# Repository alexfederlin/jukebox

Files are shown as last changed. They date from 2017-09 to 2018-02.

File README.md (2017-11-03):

# Kid's Jukebox
Here you will find all resources I used to build my RFID jukebox project.
Jukebox

(All pictures shown here are part of this [Google Photo Album](https://photos.app.goo.gl/Ljl14TL1XvXTWub62))

## TL;DR
It's a box which reads an RFID card, translates it into a folder on the Raspi's SD Card and instructing mpd to play it. You also have a display, buttons and a knob.

SW is written in bad node.js. If you just want to use it, all you need is to put the hardware together. There are Ansible playbooks which do all of the Raspi configuration and installation in the repo.
For building the hardware, there are complete instructions below and building plans in the repo. 

## Inspiration
The idea is not new. Instead of having CDs scratched in no time or paying ridiculous amounts of money for commercial RFID story players (has anyone ever bought a tonies? Really?), I decided to roll my own.

There are several good ideas for building RFID Jukeboxes out there:

They range from minimal viable products:
https://mwiedemeyer.de/blog/post/Raspberry-Pi-Jukebox-fur-Kinder

To quite sophisticated ones.
- http://www.forum-raspberrypi.de/Thread-projekt-jukebox4kids-jukebox-fuer-kinder
- http://www.forum-raspberrypi.de/Thread-projekt-rfid-media-player

## Parts
I decided the minimum for me would be the following in terms of hardware (all prices indicated are approximately what I paid in 2017, including shipping where applicable)
### Basics
- Box (Zeller-Holzkisten 30x20x15) - 6,50 EUR - hardware store
    - covers for the sides (I used metal mesh from a beat up IKEA waste paper basket)
    - front (7mm plywood from the hardware store) 
    - some more 1x2 cm wooden slats and some more plywood to mount the internal components
- Speakers, Amp (still had some small active speakers lying around)
- Raspi (still had a v1 lying around)
- Power supply (15W/5V MeanWell, RS-15-5) -  10 EUR - Amazon
- RFID reader (RDM630 UART 125KHz EM4100) - 8 EUR - Amazon
- another RFID reader for provisioning (SODIAL(R) USB RFID DeskTop ID Card Reader) - 5 EUR - Amazon
- 3 Arcade buttons (2 blue, 1 red) -  10 EUR - ebay
- 1 rotary encoder (KY-040 incl. nut) - 3 EUR incl shipping - ebay
- Ground loop insulator (AUKEY) - 10 EUR - Amazon https://www.amazon.de/gp/product/B01LX0H29W

### Small parts
- Ethernet connector (0.3m RJ45 Plug to Jack Panel Mount) - 4 EUR - ebay 
- USB cable (A to L shaped B connector) - 4 EUR - ebay
- ICE Socket C14 Inlet with switch and fuse - 4 EUR - ebay
- Some M3 screws and nuts - 9 EUR - ebay
- Resistors, capacitors - 2 EUR - ebay
- Jumper cable (some shorter, some up to 30 or 40 cm)
- heat shrinking tube

No arduino, no display.

However, what fun would it be without an Arduino?

So I scrapped that idea, or rather, I extended it.

### Extension
- Arduino Uno (used to control RFID reader, Buttons, Rotary dial, eventually an LCD) 23 EUR - Amazon
- Proto Shield V5 Prototyping Board für Arduino Uno - 6 EUR - ebay
- Display (16x2 Zeichen + I2c Modul) - 7 EUR - ebay
- Relais 2-Channel 5V Relais with Optokoppler - 5 EUR - ebay
- Wifi Stick (Edimax EW-7811Un) - 7 EUR Amazon

### Price
So, if you tally this up, not exactly cheap. 
Bare bones 75 EUR
Extensions 48 EUR
Total: 123 EUR

And this is without the Raspi, speakers and amp, since I had all of this still lying around...

Add to that maybe 100 hours of research, design, building, programming... But the learning experience was priceless :-)

## Hardware
Putting together the hardware components was a combination of woodwor and electronics. With this you have to choose the order of what you're doing wisely. Else you end up with a lot of wood shavings on your electronics parts...
### Box
A basic wooden box from the hardware store (Bauhaus).  In each corner I glued some 1x2cm wooden slates. These were cut to length so that the 7mm plywood front ended up flush with the rim of the box. 
On the sides of the box are holes, so you can carry it (if you use it as an actual storage box. They're handy for ventilation, but you'll want to cover them to keep out sticky things and pokey fingers. I cut up a beat up steel mesh waste paper basket from Ikea and upcycled the mesh for this purpose. I used a staple gun to fix it to the inside of the box.

#### Front Panel
I had the plywood for the front cut to size in the hardware store. If you have a buzz saw, you can probably do it yourself, but with a jigsaw - forget it. The front I set into the box and is screwed into the slats in the corners.
Before you do that, all the components have to be fixed to it of course. The layout of the front panel you can find as a draw.io sketch in the Documentation folder of this repo.

Front panel in intermediate stage

The front panel holds 
- the speakers
- amp
- display
- 3 arcade buttons (forward, back, play/pause)
- a rotary encoder (volume)
- the RFID reader along with its Antenna 
- Arduino.

Having all these components together on the front panel has the advantage that there are only 4 cables connecting the front panel and the back plane: 
- USB cable (Arduino - Raspi)
- Audio cable (Amp - Raspi)
- Power for the Amp (throught the Relais)

##### Tools and manufacturing
Front panel

The front panel requires a number of holes to be drilled and cut out. Tools used were
- drill 3.5 mm
- sink bit 3mm to get the screws flush with the wood
- Forstner drill 30 mm for Arcade buttons
- Holesaw 45mm for speakers
- large drill and jigsaw for the display cutout
- industrial rotary tool (Proxxon IBS) for removing some material on the back side to fit the display

shaving on the back

When cutting out the holes for the speakers - cut the big holes first, before you drill the screw holes. Once you have the big holes in place, put the speakers on there and mark where the screw holes need to go. I did it all at once just with measurements and of course my speakers now sit off-center on the holes...

#### Back plane
As back plane I used another piece of plywood. This one I cut myself, because you can't see it anyway, so it's ok if the edges are a bit squiggly. I glued some scrap pieces of plywood to the bottom of the box so it's raised up a bit. I put in some screws at an angle that go into the corner slats to hold it in place.

The picture below was taken when I tried to figure out what goes where on the backplane. Nevermind the funny cutout in the upper part. I was practicing for the display cutout on the front...
Backplane intermediate

The backplane only holds
- the Raspberry
- power supply
- power relais

I used the lower snap-in half of a Raspi case to hold the Rasperry. This is quite nice because only the case is screwed to the back plane and the Raspi itself is easily removed. That makes e.g. changing the SD card much easier.
The other components are just strapped to the plywood using cable ties threaded through holes I drilled into the plywood.

There is also a cut out for the only components that are actually attached to the box itself:
- the C14 power inlet
- the RJ45 panel mount
- the power button i didn't get around to installing

Back

### Power
The power setup is not quite finished. The inital plan was to have a power button on the back which shuts down the raspi and powers off the amp with a short press. Powering on the raspi would have to be done by physically cutting the power.
I even have the script in the repo which would have to run on the raspi, watching for the button to be pushed. But, alas, I couldn't be bothered.
I still wired the amp to the relais (which is controlled by the Raspi), so in theory I could turn off the amp if no music is playing for a while...

### Electronics

Now that we got all of that boring woodwork out of the way, now for the fun part...
Full

#### Arduino

There is a Fritzing sketch in the Documentation folder of this project...

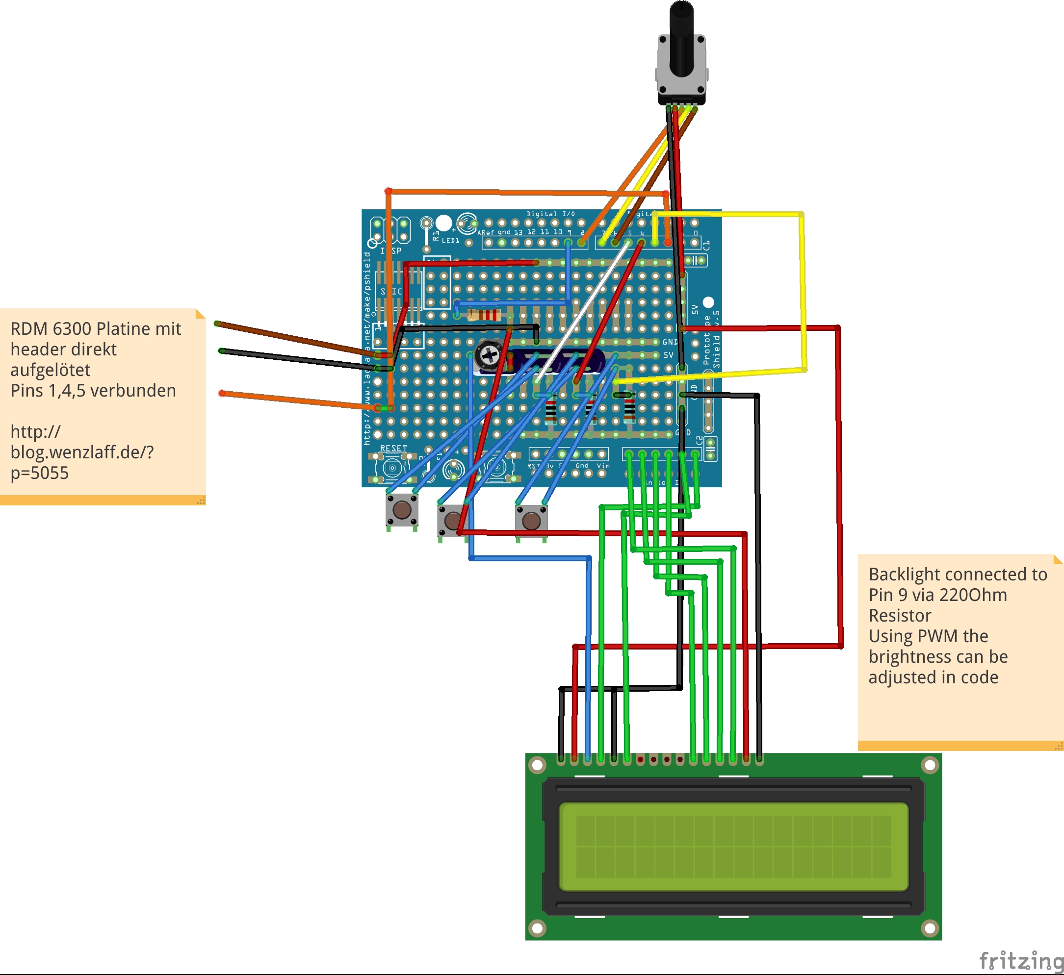
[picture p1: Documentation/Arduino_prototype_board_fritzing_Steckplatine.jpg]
Fritzing


There are a couple of things to connect to the Arduino:
- 3 Buttons
- a KY40 Rotary Encoder
- a display
- and of course the RFID reader

I use the prototyping board that you can plug on top of the Arduino to solder all my circuitry. It's all a bit small and it's not pretty, but it is absolutely doable (I'm not really a wizard with the soldering iron).And it's probably less prone to cables coming loose than breadbords - which you also would have to glue to the front panel somehow...

Arduino

##### Buttons
I decided to go with a hardware debounce for the buttons. For this I used a 1uF capacitor and a 10kOhm resistor. Why do it in hardware? Because I can. In retrospect, it probably would have been easier to do it with less hardware elements for space reasons, but hey, it works.

##### Rotary Encoder
I had a bit of a hard time with the rotary encoder for adjusting the volume. I found out that there are different hardware versions available. Some have a thread and a nut with which you can fix them to a panel. Some don't...
I also tried HW debouncing, but that didn't work. I tried a gazillion libraries that all claim to do SW debouncing for rotary encoders... luckily I found one that worked. More on that in the SW section.

##### Display
The display is a fun thing to play with. In the final product it's of less use than I thought. I tried scrolling text, but it looks horrible. So you're really confined to 2x16 characters. And putting some sensible stuff on there is more effort than I was prepared to spend to this point.
All the pins needed to drive the display are connected to the Arduino using long jumper wires. I soldered a pin strip to the display board to be able to just plug them on.

##### RFID reader
The RFID reader comes with a small board of its own which you need to connect. Since I was too lazy to figure out a way to secure it to the front panel, I simply soldered it onto the prototyping board and connected it up that way (the upside down board one the left on the picture above).
I used hot glue to stick the RFID antenna to the front panel and to stabilize the connection between the actual antenna and the cable leading to the reader board. These braids are so fine I was worried they'll break before I can fix them.

## Software
The whole thing is based on the Music Player Daemon mpd. In theory you scrap the whole interface on the box and just control the whole thing with [M.A.L.P.](https://play.google.com/store/apps/details?id=org.gateshipone.malp) or some other mpd remote control app. 
But of course that wouldn't be as much fun. So we have to roll our own for hooking up all that interface stuff.

### General Architecture
So in general, there are 4 components that interact somehow:
- The Arduino - handling the front end user interface and presentation layer (aka Display)
- The Arduinogateway - the code translating user input from the Arduino to commands to the mpd (and info back to the display)
- The Playlist Mapper - handling the database to translate an RFID tag to a path which the mpd can play
- The mpd - playing the actual music

### Arduino Sketch
The Arduino folder is actually a complete [platform.io](http://platformio.org/) project. It enables you to write your changed Arduino sketch stright to the Arduino from the Raspberry. No more clunky Arduino IDE. It will even download and install all the necessary libraries automatically. I love it.

Anyway, there's quite a bit going on in the sketch, so let's check it out component by component
#### Display
I use the [LiquidCrystal](https://www.arduino.cc/en/Tutorial/LiquidCrystalDisplay) [Library](https://www.arduino.cc/en/Reference/LiquidCrystal), which is easy enough to use. As I mentioned, scrolling looks horrible because the display is so slow to switch on and off. Pixels which are used from one step to the next remain really bright, while the others are pretty dim. The result is pretty much garbled. Anyway, if you want to try it, [this sketch proposed by Goet](https://forum.arduino.cc/index.php?topic=216486.msg3338710#msg3338710) seems to work pretty well...

One thing that I think is pretty neat is the automatic backlight dimming I implemented using the PWM pin on the Arduino. By hooking up the backlight pin of the displa to one of the "analog" pins of the Arduino, I'm able to dim the backlight in the code. It goes bright at any input, and dims after there hasn't been any input for 10 seconds.

#### Serial Connection
Using SoftwareSerial for the serial connection to the Raspi through the USB cable. The Arduino is also powered through the USB cable.
The protocol between the Arduino and the Raspi (Arduinogateway process) is extremely simple. There are 5 commands which the Arduino can send to the Raspi:

- CMD: setvol xx
- CMD: previous
- CMD: next
- playpause
- RFID: xxxx

The ones prefixed by CMD: are piped verbatim to the mpd by the Arduinogw. The others need to be handled separately.

playpause: The Arduino does not know whether the player is currently playing or not (I guess you could implement it in a way that the Arduino gets informed of the state and stores that state. But whatever). So if the play/pause button is pressed, this tells the Arduinogw process that it should toggle the play/pause state of the player. More on that in the ArduinoGW section

RFID: xxxx: with this the Arduinogw process needs to find out which command/playlist is attached to that RFID before being able to send it.

Everything else that is sent will just be logged by Arduinogw. 

For the return communication, I decided to terminate each command or piece of information sent to the Arduino with a new line. That way I can deal with incoming messages in one piece and don't have to manually find out if what I've received so far makes sense or not. Everything the Arduino receives on the serial connection is printed on the display and sent back to Arduinogw.

#### Rotary Encoder
Rotary Encoders are pretty cool. [Here is how they work](http://henrysbench.capnfatz.com/henrys-bench/arduino-sensors-and-input/keyes-ky-040-arduino-rotary-encoder-user-manual/).
But oh boy, getting them to work properly is not easy. I tried many libraries for rotary encoders. None really worked. Then I found the [stuff the boolrules posted](https://forum.arduino.cc/index.php?topic=242356.msg2308019#msg2308019). I have no idea what it does, but I was able to integrate it and it works like a treat. It has two modes (interrupt and polling), I use it in polling mode and have thrown away the unused interrupt code.
Some code in the loop section takes care that you cannot turn the volume up to 11. Well actually you can increment and decrement in steps of 10 between 0 and 100. Why not 1-10? Laziness. That way I can push the value through all the way to mpd.

#### Buttons
The button stuff is pretty straight forward. There is is three buttons connected to three input pins. If a button is pressed, we send the appropriate command. And we do not send any other button event until that initial button is released. Mainly, this prevents repeatedly sending the same command as long as the button is pushed. As a side effect, pushing several buttons at once does not have any effect. There is only one button command sent.

#### RFID reader
The RFID reader code needs to deal with some special cases. 
The RFID reader will repeat the RFID it has in range every couple 100 ms as long as it is in range. Of course we only want to send the command to play a given RFID tag only once. So there is a blocktimer of 5 seconds during which the same RFID tag is ignored.
At the same time I found that the  RFID reader sometimes spits out random RFID tags. But these are not repeated. So if a RFID tag is read, it will actually be ignored the first time. Only if the RFID reader signals again within 1 second, we actually look at what has been sent.

The format in which the RFID reader signals the IDs got me stumped initially, since it just wasn't what I expected. Also my hex is quite rusty. It takes some bit shifting to actually get a decimal number out of what you get from the RFID Reader.

##### Expectation
At first I somehow expected the individual decimal digits to be hex encoded. So I expected something like this:

Consider the following RFID tag in decimal: 0007616525
In ASCII this would actually be the following binary octets:

    0011 0000 
    0011 0000 
    0011 0000 
    0011 0111 
    0011 0110 
    0011 0001 
    0011 0110 
    0011 0101 
    0011 0010 
    0011 0101

Now we remove the leading 0011s

    0000 
    0000 
    0000 
    0111 
    0110 
    0001 
    0110 
    0101 
    0010 
    0101

and concatenate the remaining half octets (nibbles) together to new bytes

    0000 0000  0x0
    0000 0111  0x7
    0110 0001  0x61
    0110 0101  0x65
    0010 0101  0x25

##### Reality

In reality, what you get from the RFID reader is of course the complete number (7 mio 616 thousend 525) in hex:

    0111 0100  0x74
    0011 1000  0x38
    0000 1101  0x0D

The format in which you get it is an array of bytes, so actually:

    data[1] = 0x00
    data[2] = 0x74
    data[3] = 0x38
    data[4] = 0x0D

So, in order to convert this to a usable decimal number (because that's what I want, the RFID is printed on the card in decimal as well), there is a bit of casting and bit shifting to do.

     unsigned long result = ((unsigned long int)data[1]<<24) + ((unsigned long int)data[2]<<16) + ((unsigned long int)data[3]<<8) + data[4];
     
First of all, we need to cast all of this to unsigned long int in order to be even able to shift it that far.
So we convert the byte in data[1] to an unsigned long and shift it by 24 bits to the left. Not really exciting because it's all 0.
But now we take the contents of data[2] and shift it 16 bits. So we take

    0111 0100

convert it to

    0000 0000 0000 0000 0000 0000 0111 0100
    
and then bit shift it by 16 bits:

    0000 0000 0111 0100 0000 0000 0000 0000

to that we add the contents of data[3], shifted by 8 bits:

    0000 0000 0111 0100 0011 1000 0000 0000

And then we also add the contents of data[4]:

    0000 0000 0111 0100 0011 1000 0000 1101
    
So, if we output this in its decimal representation we get what we want...

### Raspberry

#### Arduino Gateway

This is the main controlling component of the Jukebox. The actual playback of media files is handled by mpd.
This process listens to the input coming from the Arduino on the serial connection.
The commands are partly passed on directly to mpd, partly they are pre processed before the required requests are sent to mpd

There are three types of messages that can come from the Arduino
1. button presses
   button presses can result in three different messages
   - prev
   - next
   - playpause
   The first two can be put through to the mpd server. Playpause first needs to determine the current status of playback (play, stop, pause) and will then send either 
   - pause (if current status is play) 
   - play (if current status is anything else)

2. Volume messages
   volume messages are sent by the Arduino the form of volume/<value>
   This is the format expected by mpd and can be sent straight on
3. RFID reads
    If an RFID tag is scanned the message will look like: "RFID: <rfidTag>"
    First of all, we need to figure out which playlist is connected to this RFID tag. This is done by the process playlistmapper, listening on the given port and expects the RFID tag. It will reply with the appropriate playlist/folder name which will be sent to mpd.

Requirements:
- mpd must be running and it's library up to date
- playlistmapper must be running and configured to translate RFID tags to playlists present in mpd

#### Playlist mapper

Playlistmapper is a simple web server based on nodejs express which also interacts with a DB backend (a very simple file handled by nedb).
The DB stores the relation between the RFID tags and the playlist/Folder names. 
It exposes a REST interface which enables querying for a certain RFID tag.
The reply is provided in the form of a JSON String including the RFID tag as well as the playlist name: {"rfid":"7616525","playlist":"plA"}

## Deployment
If you have a Linux or Mac system, you can just follow the instructions below. If you're on Windows, you'll have to make Ansible run as Control node [somewhere somehow](http://www.tomsitpro.com/articles/how-to-use-ansible-on-windows,1-3479.html). 

1. On your main PC: install Ansible
2. PC: clone this git repo
3. Raspi: install latest Raspian light
3. Raspi: [enable ssh access](https://www.raspberrypi.org/documentation/remote-access/ssh/) and make sure you can login to the Raspi from your main PC
4. PC: make sure you have an ssh key and install it on the Raspi: `cat ~/.ssh/id_rsa.pub | ssh pi@raspberry 'mkdir .ssh && cat >> .ssh/authorized_keys'` or simply `ssh-copy-id pi@raspberry`
5. PC: enter the IP of your raspi in the ansibles inventory
6. PC: start the playbooks in order 1-3. 

### Ansible Playbooks
- 01:
  - set password of user pi to: jukebox
  - force apt to use IP4 (else apt installation does not work for me)
  - force audio through 3,5mm jack
  - do apt update / upgrade and install several packages
  - download and install node.js 7.9.0
  - instructs mpd to update its database
- 01a: You can skip 01a if you do not have an extra partition for your music (see multi-partition setup below).
- 02: clone this git repo and install the necessary nodejs modules
- 03: Sets up the necessry services to be started at boot and starts them
- 04: is only needed if you want to use rsync to sync a music folder on your main (or other) PC to the jukebox.

If all the playbooks went through without error, everything should be installed and configured and all services should be up and running on the raspberry.
There are a couple of optional playbooks which 
- opt01/a: allow you to switch back and forth between a USB sound card and the built-in 3.5 jack audio output
- opt02: Installs [platformio](http://platformio.net) on the raspi (for flashing your Arduino straight from the Raspi)

## Operations

## Provisioning

# Special cases
## Multi-Partition setup.
I like to have my music on another partition than the root system. In case I need to reinstall the system, I don't have to re-upload all of the music. Having multiple partitions on a raspi system is not quite as straightforward as I'd hoped. 
In general Raspbian resizes the root partition to fill the whole medium at the first boot. It does not do this, if another partition is already present on the device. In that case, the root partition of the raspi is too small to install anything extra. So you have to enlarge it manually. After doing that, the PARTUID has changed, so you need to update the /boot/cmdline.txt and /etc/fstab on your raspi system...

### WARNING - HERE BE DRAGONS
In the following I'll describe how I set it up. You'll have to think for yourself what you are doing! I take no responsibility for any wiped harddrives...

1. Download latest raspbian (
2. check if download is correct `sha256sum 2017-08-16-raspbian-stretch-lite.zip`
3. unzip raspbian image `unzip 2017-08-16-raspbian-stretch-lite.zip`
4. put on SD Card - MAKE SURE YOU SPECIFY THE CORRECT DEVICE AS of=/dev/sxx `sudo dd if=2017-08-16-raspbian-stretch-lite.img of=/dev/sxx bs=1M`
5. create additional partition on sdcard for music `fdisk /dev/sxx`
    If you start fdisk and [p]rint all partitions, you will find something like this:
```
Medium /dev/sdd: 59,5 GiB, 63864569856 Bytes, 124735488 Sektoren
Einheiten: sectors von 1 * 512 = 512 Bytes
Sektorengröße (logisch/physisch): 512 Bytes / 512 Bytes
I/O Größe (minimal/optimal): 512 Bytes / 512 Bytes
Typ der Medienbezeichnung: dos
Medienkennung: 0xee397c53

Gerät      Boot Start    Ende Sektoren Größe Id Typ
/dev/sdd1        8192   93813    85622 41,8M  c W95 FAT32 (LBA)
/dev/sdd2       94208 3621911  3527704  1,7G 83 Linux
```
or, if you want to use parted
```
$ sudo parted /dev/sdd
GNU Parted 3.2
/dev/sdd wird verwendet
Willkommen zu GNU Parted! Rufen Sie »help« auf, um eine Liste der verfügbaren Befehle zu erhalten.
(parted) p                                                                
Modell: Generic STORAGE DEVICE (scsi)
Festplatte  /dev/sdd:  63,9GB
Sektorgröße (logisch/physisch): 512B/512B
Partitionstabelle: msdos
Disk-Flags: 

Nummer  Anfang  Ende    Größe   Typ      Dateisystem  Flags
 1      4194kB  48,0MB  43,8MB  primary  fat32        LBA
 2      48,2MB  1854MB  1806MB  primary  ext4
```

As you can see, the raspi partition is only 1,7 Gb. There will most likely a lot of empty space on your device left. If you boot this now, raspian will automatically resize the root partition to take up the whole device. 

What you actually want is a root partition which is 5-6GB and another partition which takes up the remaining space on the device for your data. 

So you need to delete the root partition, recreate it with the same start boundary, but a bit larger, and then create another partition for your data taking up the rest of the space (or however much you like)

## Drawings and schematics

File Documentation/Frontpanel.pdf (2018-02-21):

# Front View

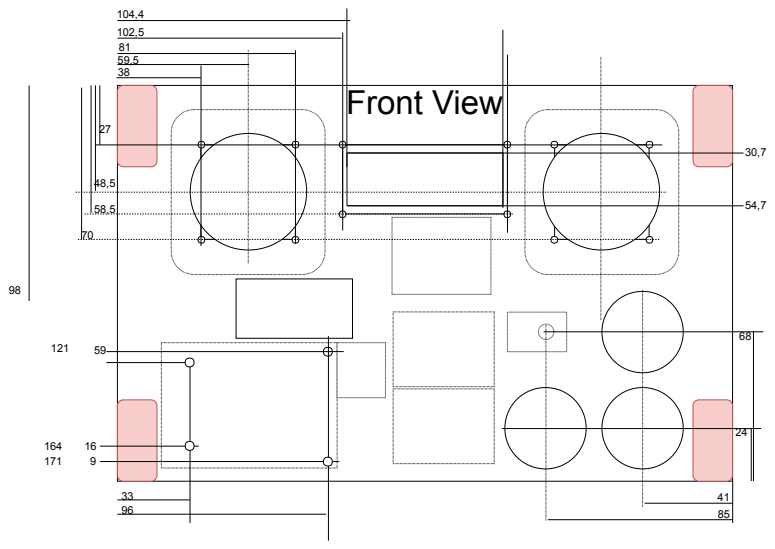
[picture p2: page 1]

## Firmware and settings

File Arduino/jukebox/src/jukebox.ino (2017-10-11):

/*
 *      based on 
 *      - Rotary Encoder: http://www.buxtronix.net/2011/10/rotary-encoders-done-properly.html
 *      - RFID Handling:  http://playground.arduino.cc/Main/RDM630RFIDReaderLibrary
 *      
 */


#include    <MsTimer2.h>
#include <SoftwareSerial.h>
#include "rdm630.h"
#include <LiquidCrystal.h>
#include <Wire.h>


// initialize the library with the numbers of the interface pins
LiquidCrystal lcd(A0, A1, A2, A3, A4, A5);
int lcdBacklightPin = 9;
#define LCDWIDTH 16
#define LCDHEIGHT 2

String pinnedString = "online";
String scrollingString = "The Jukebox is";
int pinnedRow = LCDHEIGHT / 2;
int scrollingRow =  LCDHEIGHT / 2 - 1;
int scrollingSpeed = 400;


byte playicon[8] =
{
  0b10000,
  0b11000,
  0b11100,
  0b11110,
  0b11110,
  0b11100,
  0b11000,
  0b10000
};

byte pauseicon[8]  = {
  0b00000,
  0b11011,
  0b11011,
  0b11011,
  0b11011,
  0b11011,
  0b11011,
  0b00000
};

byte stopicon[8] = {
  0b00000,
  0b00000,
  0b11111,
  0b11111,
  0b11111,
  0b11111,
  0b11111,
  0b00000
};

int lcdCurBrightness = 0;
unsigned long lcdLastRaise;

// Rotary Encoder Stuff
///////////////////////////////////////////////////////////////////////////////

#define DIR_NONE 0x00           // No complete step yet.
#define DIR_CW   0x10           // Clockwise step.
#define DIR_CCW  0x20           // Anti-clockwise step.

unsigned int A = 6;             // pins connected to the encoder (CLK)
unsigned int B = 7;             //              "                (DT)
unsigned int ISRflag = 8;       //              "                (SW)

unsigned int state;
         int count = 40;         // count each indent
         int old_count = 0;     // check for count changed
const String VOLUME = "CMD: setvol ";
String vol = VOLUME;
/*
 * The below state table has, for each state (row), the new state
 * to set based on the next encoder output. From left to right in,
 * the table, the encoder outputs are 00, 01, 10, 11, and the value
 * in that position is the new state to set.
 */

// State definitions state table (emits a code at 00 only)
// states are: (NAB) N = 0: clockwise;  N = 1: counterclockwiswe
#define R_START     0x3
#define R_CW_BEGIN  0x1
#define R_CW_NEXT   0x0
#define R_CW_FINAL  0x2
#define R_CCW_BEGIN 0x6
#define R_CCW_NEXT  0x4
#define R_CCW_FINAL 0x5

const unsigned char ttable[8][4] = {
    {R_CW_NEXT,  R_CW_BEGIN,  R_CW_FINAL,  R_START},                // R_CW_NEXT
    {R_CW_NEXT,  R_CW_BEGIN,  R_CW_BEGIN,  R_START},                // R_CW_BEGIN
    {R_CW_NEXT,  R_CW_FINAL,  R_CW_FINAL,  R_START | DIR_CW},       // R_CW_FINAL
    {R_START,    R_CW_BEGIN,  R_CCW_BEGIN, R_START},                // R_START
    {R_CCW_NEXT, R_CCW_FINAL, R_CCW_BEGIN, R_START},                // R_CCW_NEXT
    {R_CCW_NEXT, R_CCW_FINAL, R_CCW_FINAL, R_START | DIR_CCW},      // R_CCW_FINAL
    {R_CCW_NEXT, R_CCW_BEGIN, R_CCW_BEGIN, R_START},                // R_CCW_BEGIN
    {R_START,    R_START,     R_START,     R_START}                 // ILLEGAL
};





//Button stuff
///////////////////////////////////////////////////////////////////////////////

const int buttonPin_back = 3;     // the number of the pushbutton pin
const int buttonPin_play = 4;     // the number of the pushbutton pin
const int buttonPin_forward = 5;     // the number of the pushbutton pin
const int ledPin =  13;      // the number of the LED pin

int buttonState_back = 0;         // variable for reading the pushbutton status
int buttonState_play = 0;         // variable for reading the pushbutton status
int buttonState_forward = 0;         // variable for reading the pushbutton status
int sentstate = 0;


//RFID Stuff
///////////////////////////////////////////////////////////////////////////////

rdm630 rfid(2, 0);  //TX-pin of RDM630 connected to Arduino pin 2
unsigned long time;
unsigned long lastTime;
unsigned long elapsedTime;
unsigned long blocktimer;
byte lastdata[6];
bool block;


// Serial stuff
/////////////////////////////////////////////////////////////////////////////// 
String incomingString = "";


// Helper Methods
///////////////////////////////////////////////////////////////////////////////

// Timer method for Rotary Encoder polling
void T2_isr( ) {

    // Grab state of input pins.
    unsigned char pinstate = (digitalRead( A ) << 1) | digitalRead( B );

    // Determine new state from the pins and state table.
    state = ttable[state & 0x07][pinstate];

    if( state & DIR_CW )    count=count+10;        // count up for clockwise
    if( state & DIR_CCW )   count=count-10;        // count down for counterclo$

}


void lcdDim( ) {
  int lowest = 20;
  for (int fadeValue = lcdCurBrightness ; fadeValue >= lowest; fadeValue -= 5) {
    // sets the value (range from 0 to 255):
    analogWrite(lcdBacklightPin, fadeValue);
    // wait for 30 milliseconds to see the dimming effect
    delay(30);
  }
  lcdCurBrightness = lowest;
}

void lcdRaise( ) {
  int highest = 255;
  for (int fadeValue = lcdCurBrightness ; fadeValue <= highest; fadeValue += 5) {
    // sets the value (range from 0 to 255):
    analogWrite(lcdBacklightPin, fadeValue);
    delay(5);
  }
  lcdCurBrightness = highest;
  lcdLastRaise = millis();
}

void lcdDisplay(String str) {
  lcd.clear();
  lcd.setCursor(0, 0);
  lcd.print(str);
}


// read from Serialport until a CR is found
// see https://hackingmajenkoblog.wordpress.com/2016/02/01/reading-serial-on-the-arduino/
int readline(int readch, char *buffer, int len)
{
  static int pos = 0;
  int rpos;

  if (readch > 0) {
    switch (readch) {
      case '\n': // Ignore new-lines
        break;
      case '\r': // Return on CR
        rpos = pos;
        pos = 0;  // Reset position index ready for next time
        return rpos;
      default:
        if (pos < len-1) {
          buffer[pos++] = readch;
          buffer[pos] = 0;
        }
    }
  }
  // No end of line has been found, so return -1.
  return -1;
}


/* This procedure pins a given text in the center of a desired row while scrolling from right to left another given text on another desired row.
    Parameters:
    const String &pinnedText: pinned String
    int pinnedRow: desired row for pinned String
    const String &scrollingText: scrolling String
    int scrollingRow: desired row for scrolling String
    int v = scrolling speed expressed in milliseconds
*/
void pinAndScrollText(const String &pinnedText, int pinnedRow, const String &scrollingText, int scrollingRow, int v) {
  if (pinnedRow == scrollingRow || pinnedRow < 0 || scrollingRow < 0 || pinnedRow >= LCDHEIGHT || scrollingRow >= LCDHEIGHT || pinnedText.length() > LCDWIDTH || v < 0) {
    lcd.clear();
    lcd.print("Error");
    while (1);
  }
  int l = pinnedText.length();
  lcd.setCursor(l % 2 == 0 ? LCDWIDTH / 2 - (l / 2) : LCDWIDTH / 2 - (l / 2) - 1, pinnedRow);
  lcd.print(pinnedText);
  int x = LCDWIDTH;
  int n = scrollingText.length() + x;
  int i = 0;
  int j = 0;
  while (n > 0) {
    if (x > 0) {
      x--;
    }
    lcd.setCursor(x, scrollingRow);
    if (n > LCDWIDTH) {
      j++;
      i = (j > LCDWIDTH) ? i + 1 : 0;
      lcd.print(scrollingText.substring(i, j));
    } else {
      i = i > 0 ? i + 1 : 0;
      if (n == scrollingText.length()) {
        i++;
      }
      lcd.print(scrollingText.substring(i, j));
      lcd.setCursor(n - 1, scrollingRow);
      lcd.print(' ');
    }
    n--;
    if (n > 0) {
      delay(v);
    }
  }
}


// Setup
///////////////////////////////////////////////////////////////////////////////
///////////////////////////////////////////////////////////////////////////////

void setup( ) {

//initialize LCD
    lcdRaise();
    lcd.createChar(0, playicon);
    lcd.createChar(1, pauseicon);
    lcd.createChar(2, stopicon);
    lcd.begin(16, LCDHEIGHT);

  //pinAndScrollText(pinnedString, pinnedRow, scrollingString, scrollingRow, scrollingSpeed);

//  delay(2000);
  lcd.clear();
//  lcd.print("Back");

    
// initialize the Rotary Encoder
    // pins as an input
    pinMode( A, INPUT );
    pinMode( B, INPUT );
    // start interrupt polling
    MsTimer2::set( 1, T2_isr );
    MsTimer2::start( );
    state = (digitalRead( A ) << 1) | digitalRead( B );     // Initialise state.
    old_count = 0;

//set up visual feedback for button push and RFID action
    pinMode(ledPin, OUTPUT);      

// initialize the pushbutton pin as an input:
    pinMode(buttonPin_back, INPUT);
    pinMode(buttonPin_play, INPUT);     
    pinMode(buttonPin_forward, INPUT);  


// initialize RFID
    rfid.begin();
    time = millis();
    lastTime = millis();
    blocktimer = 0L;

// initialize Serial connection

    Serial.begin( 9600 );
    Serial.println( "Jukebox Input Module Online" );
    Serial.setTimeout(200);

// Print a message to the LCD.
    lcdDisplay("Jukebox Online");
//    lcd.setCursor(15,0);
//    lcd.write((uint8_t)2);
}


// Loop
///////////////////////////////////////////////////////////////////////////////
///////////////////////////////////////////////////////////////////////////////

void loop( ) {

//read from serial

  static char buffer[80];
  if (readline(Serial.read(), buffer, 80) > 0) {
    Serial.print("Data received by Arduino: >");
    Serial.print(buffer);
    Serial.println("<");
    lcdDisplay(buffer);
  }

// Rotary Encoder 
    if( old_count != count ) {
        if ( count > 100 ) {
          count=100;
          return;
        }
        if ( count < 0) {
          count=0;
          return;
        }
        vol = VOLUME + count; 
        Serial.println(vol);
        //lcdDisplay(vol);
        old_count = count;
        lcdRaise();
        lcdDisplay ("Lautstaerke: " + String(count));
    }

//Pushbuttons
  // read the state of the pushbutton value:
  buttonState_back = digitalRead(buttonPin_back);
  buttonState_play = digitalRead(buttonPin_play);
  buttonState_forward = digitalRead(buttonPin_forward);
  
  
  // check if the pushbutton is pressed.
  // if it is, the buttonState is HIGH:
  if ((buttonState_back == HIGH) && (sentstate == 0)) {     
    // turn LED on:    
    digitalWrite(ledPin, HIGH);
    Serial.println("CMD: previous");
    lcdDisplay("previous");
    sentstate = 1;
    lcdRaise();
  } 
  else if ((buttonState_play == HIGH) && (sentstate == 0)) {     
    // turn LED on:    
    digitalWrite(ledPin, HIGH);  
    Serial.println("playpause");
    //lcdDisplay("playpause");
    lcd.setCursor(15,0);
    lcd.write((uint8_t)0);
    sentstate = 1;
    lcdRaise();
  }
  else if ((buttonState_forward == HIGH) && (sentstate == 0)) {     
    // turn LED on:    
    digitalWrite(ledPin, HIGH);  
    Serial.println("CMD: next");
    lcdDisplay("next");
    sentstate = 1;
    lcdRaise();
  }
  else if ((buttonState_back == LOW) && (buttonState_play == LOW) && (buttonState_forward == LOW)){
    // turn LED off:
    digitalWrite(ledPin, LOW); 
    sentstate = 0;
  }

// RFID stuff
    byte data[6];
    byte length;

    time = millis();

    if(rfid.available()){
        digitalWrite(ledPin, HIGH);
        if ((time - lastTime) < 1000) { // used to filter out sporadic spurious IDs
          
            rfid.getData(data,length);
            // avoid continous repetition of one and the same ID while held to reader during a block time of 5 seconds
            // output only if a different ID is read or if the block is removed
            if (memcmp(lastdata,data,length) != 0 || (time-blocktimer > 5000)) { 
              //shift the bytes to their respective positions
              //explanation why casting is needed: http://www.mikrocontroller.net/topic/95708
              unsigned long result = ((unsigned long int)data[1]<<24) + ((unsigned long int)data[2]<<16) + ((unsigned long int)data[3]<<8) + data[4];              
              Serial.print("RFID: ");
              Serial.println(result);
              //lcdDisplay(String(result));
              rfid.getData(lastdata,length);
              blocktimer = millis();
              lcdRaise();
            }
        }
        lastTime = millis();
        delay(5);
        digitalWrite(ledPin, LOW); 
    }

//  lcd.setCursor(0, 1);
  // print the number of seconds since reset:
//  lcd.print(millis() / 1000);

  if (millis() - lcdLastRaise > 10000) lcdDim();

}

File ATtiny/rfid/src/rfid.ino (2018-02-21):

#include "TinyWireS.h"
#include "rdm630.h"
//#####################################################
// This code takes care of reading RFID (RD6300)
// on an ATTiny45
// It needs to be polled from the master and will 
// return a bitmap of the last read RFID (hopefully)
//#####################################################

int ledPin = 1;

rdm630 rfid(3, 4);  //TX-pin of RDM630 connected to PB3

unsigned long time;
unsigned long lastTime;
unsigned long blocktimer;

byte data[6];
byte lastdata[6];

byte i2cAddress = 20;
int i2cSendStep = 0;
bool i2cSendComplete = true;
byte i2cSendData[6];



void setup() {

  pinMode(ledPin, OUTPUT);
  digitalWrite(ledPin, LOW);

// initialize RFID
  rfid.begin();

  time = millis();
  lastTime = millis();
  blocktimer = 0L;

  // config TinyWire library for I2C slave functionality (SDA: PB0 , SCL: PB2)
  TinyWireS.begin( i2cAddress );
  // register a handler function in case of a request from a master
  TinyWireS.onRequest( onI2CRequest );
}

void loop() {
    
    byte length;

    time = millis();

    if(rfid.available()){
        
        if ((time - lastTime) < 1000) { // throw away first read ID. Used to filter out sporadic spurious IDs

            rfid.getData(data,length);
            // avoid continous repetition of one and the same ID while held to reader during a block time of 5 seconds
            // output only if a different ID is read or if the block is removed
            if (memcmp(lastdata,data,length) != 0 || (time-blocktimer > 5000)) { 
              digitalWrite(ledPin, HIGH);  
              rfid.getData(lastdata,length);
              blocktimer = millis();
            }
        }
        lastTime = millis();
        digitalWrite(ledPin, LOW); 
    }
    // copy the latest read data to the send buffer only if we are not in the
    // process of currently sending out an RFID
    
    if (i2cSendComplete) {
      for (int i=0; i<6; i++) {
        i2cSendData[i] = data[i];
      }
    }
}

// Request Event handler function
//  --> Keep in mind, that this is executed in an interrupt service routine. It shouldn't take long to execute
void onI2CRequest()
{

  //send 0 255 0 as delimiter between two RFID tags
  if ((i2cSendStep >= 0) && (i2cSendStep < 4)) {
    i2cSendStep++;
    i2cSendComplete = false;
    TinyWireS.send(i2cSendData[i2cSendStep]);  
  }
  else {
    if (i2cSendStep >0) {
      i2cSendStep = -2;
      i2cSendComplete = true;
      TinyWireS.send(0);  
    }
    else {
      if (i2cSendStep == -2) {
        TinyWireS.send(255);
        i2cSendStep++;
      }
      else {
        TinyWireS.send(0);
        i2cSendStep = 0;
      }
    }
  }
}

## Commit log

2017-01-01 first version of Arduino code reading 3 buttons
2017-01-01 added schematic for HW debounced button
    [debounced_Button.fzz]
2017-01-09 add rip2jukebox.sh flow
2017-02-14 added arduinogw acting as gateway between serial and REST
2017-02-14 adding Arduino file handling rotary encoder
2017-02-15 added three buttons to control prev,next,play/pause on both Arduino and arduinogw
2017-02-23 renamed arduino code
2017-02-23 added RFID readout to Arduino code
2017-03-03 added proper RFID control to Arduino JukeboxIO
2017-03-04 now arduinogw is sending play request to mipod
2017-03-19 buttons and volume knob
2017-03-26 added power supply, USB power plug
2017-03-28 added power button
2017-04-15 added buildroot config and shutdown script for raspberry pi
2017-04-22 added arduino screw
2017-05-02 corrected Arduino mounting hole
2017-05-13 added Fritzing schematic for prototype shield
    [Jukebox_redux.fzz]
2017-05-21 final fritzing layout
    [Jukebox_redux.fzz]
2017-05-21 moved diagrams into Documentation folder
    [Arduino_prototype_board_fritzing.fzz]
2017-05-21 added platformio project for arduino and moved the RDM630 library in there
2017-05-21 cleaned up unused stuff in Arduino folder
2017-05-23 first start of Ansible playbook for initial deployment of stuff to Raspberry Pi
2017-05-23 added command to force audio thru 3.5mm jack to playbook
2017-05-24 changed arduingw from arduino-interface to node serial, as arduino-interface insistst that it cannot lock the port
2017-05-25 added PWM backlight dimming via Arduino Pin 9 in Fritzing diagram
    [Arduino_prototype_board_fritzing.fzz]
2017-05-25 added systemd service files for automatic startup on the raspberry
2017-05-25 added onoff to control the GPIO on the RPi which is connected to the relais powering the amp
2017-06-01 rearanged the Arduino setup function
2017-07-25 added service switching on the speakers
2017-07-27 several changes to arduino code
2017-07-28 changed arduino to include leading 0s before the rfid tag
2017-07-28 removed relaiscontrol service, as relais should be switched by arduinogw
2017-08-23 changes to Arduino sketch - scrolling text - WIP, buggy
    [jukebox.ino]
2017-08-23 added feedback to Arduino about currently playing track
2017-08-24 added mounting of music partition and modified starting of rsync daemon in Ansible scripts
2017-08-26 threw out pin and scroll for now. need to make it non-blocking, then we might be able to use it again
2017-08-31 moved from timeout based to CR based reading of serial on arduino. now adding CR on gateway side when sending message to arduino
2017-09-06 added ansible playbook to fall back to 3.5mm jack audio
2017-09-17 remove mounting of music partition
2017-11-03 added first try to use ATtinys to replace Arduino
    [buttonctrl.ino]
2017-11-03 added i2cgw folder
2017-11-03 added i2c node script
2017-11-03 i2c node adaptations
2017-11-03 button presses on ATtiny sorted
2017-11-04 reading rotary encoder values
2017-11-23 put volume and button control together
2018-01-18 getting stuff to work with i2c-bus
2018-01-22 added RFID functionality to i2cgw
2018-01-23 moved ATtiny/rotaryenc to pio project, added switch recognition
2018-02-10 changed the shutdown script because using Normally Open on the button
2018-02-19 added communication to mpd to i2cgw
2018-02-19 switch push turns display on and off
2018-02-19 added startupscript for i2cgw and matching ansible playbook
2018-02-20 changed back shutdownscript to normally open button
2018-02-21 i2c sometimes reports garbled RFIDs which caused the same playlist to start over and over again
2018-02-21 added fritzing sketch for ATTiny setup, Frontpanel pdf
    [ATtiny_941_board.fzz]
